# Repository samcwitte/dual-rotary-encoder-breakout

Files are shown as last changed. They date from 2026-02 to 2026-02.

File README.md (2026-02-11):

# dual-rotary-encoder-breakout
This is an open-source breakout PCB for the Bourns Inc. PEC11D-4120F-S0015 dual rotary encoder with switch.

This was made in KiCad 9.0.

All hardware and associated files are under the CERN Open Hardware Licence Version 2 - Permissive license.

All software and associated files are under the MIT license.

## Bill of Materials
Everything you'll need to make one yourself!

Alternative interactive BOM in `./ibom.html`

| | References | Value | Footprint | Quantity |
|---|---|---|---|---|
| 1 | R1, R2, R3, R4, R5, R6, R7, R8, R9 | 10K | 0603 (1608 Metric) | 9 |
| 2 | C1, C2, C3, C4 | 0.01u | 0603 (1608 Metric) | 4 |
| 3 | S1 | PEC11D-4120F-S0015 | PEC11D-4120F-S0015 Rotary Encoder | 1 |
| 4 | J3 | PINHD_1x7_Male | 2.54mm pitch header | 1 |

## Software Example

I used [Mike Teachman's micropython-rotary library](https://github.com/miketeachman/micropython-rotary) for some micropython code to run on a Raspberry Pi Pico.

You can find example code in `./software`. Be sure to use the latest version of Mike's library.

## 3D Render

preview-3d

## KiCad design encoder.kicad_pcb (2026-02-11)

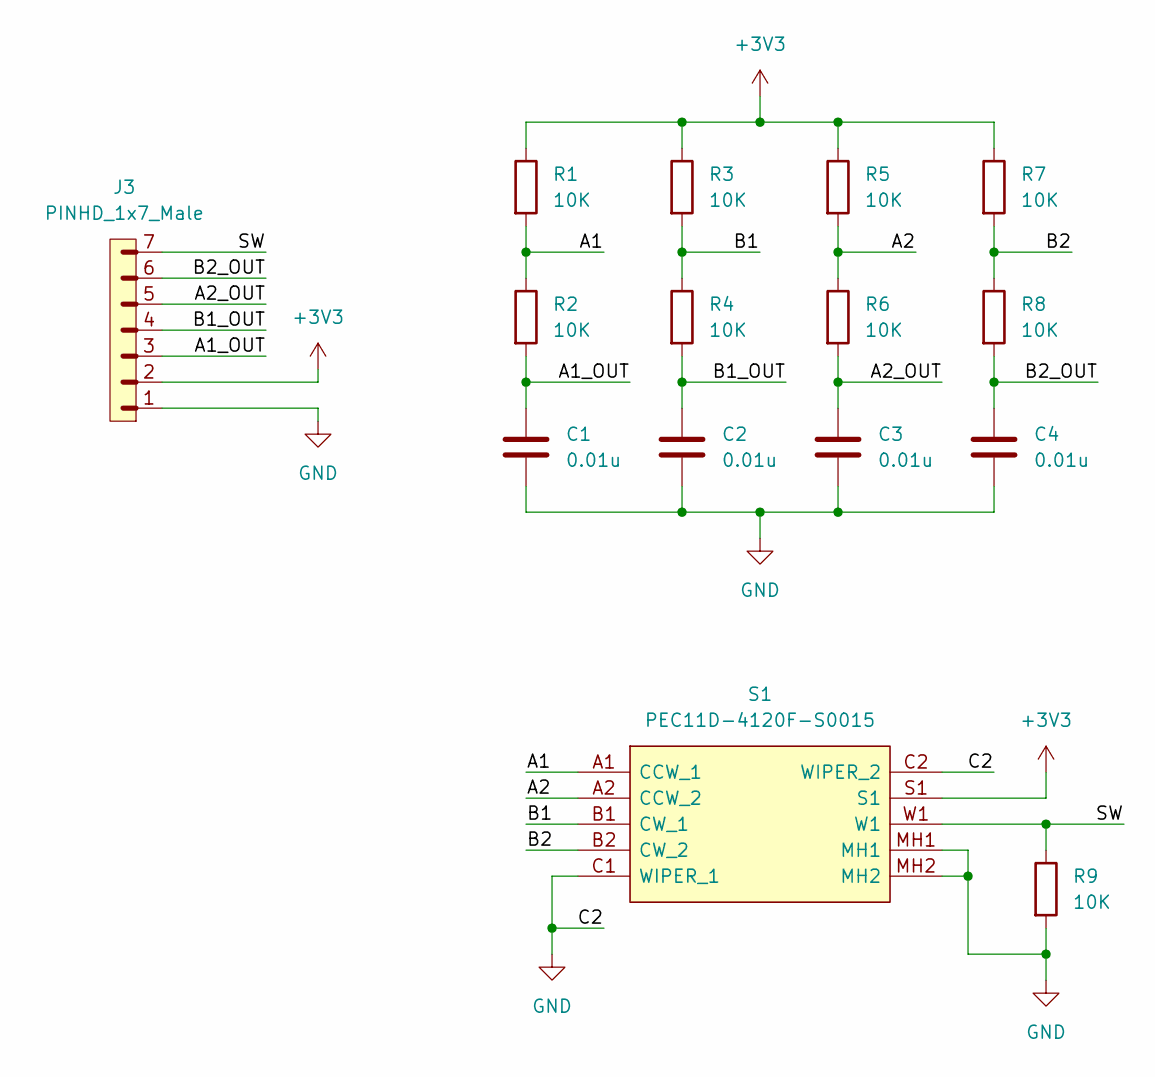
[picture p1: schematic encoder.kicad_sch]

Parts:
C1, C2, C3, C4: 0.01u; C_0603_1608Metric_Pad1.08x0.95mm_HandSolder; Part Number CL10B103KB8NNNC
J3: PINHD_1x7_Male; PinHeader_1x07_P2.54mm_Vertical
R1, R2, R3, R4, R5, R6, R7, R8, R9: 10K; R_0603_1608Metric_Pad0.98x0.95mm_HandSolder; Part Number AC0603FR-1310KL
S1: PEC11D-4120F-S0015; PEC11D-4120F-S0015 Rotary Encoder; Mouser Part Number 652-PEC11D4120FS0015

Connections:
+3V3: J3.2, R1.1, R3.1, R5.1, R7.1, S1.S1
/A1: R1.2, R2.1, S1.A1 (CCW_1)
/A1_OUT: C1.1, J3.3, R2.2
/A2: R5.2, R6.1, S1.A2 (CCW_2)
/A2_OUT: C3.1, J3.5, R6.2
/B1: R3.2, R4.1, S1.B1 (CW_1)
/B1_OUT: C2.1, J3.4, R4.2
/B2: R7.2, R8.1, S1.B2 (CW_2)
/B2_OUT: C4.1, J3.6, R8.2
/SW: J3.7, R9.1, S1.W1
GND: C1.2, C2.2, C3.2, C4.2, J3.1, R9.2, S1.C1 (WIPER_1), S1.C2 (WIPER_2), S1.MH1, S1.MH2

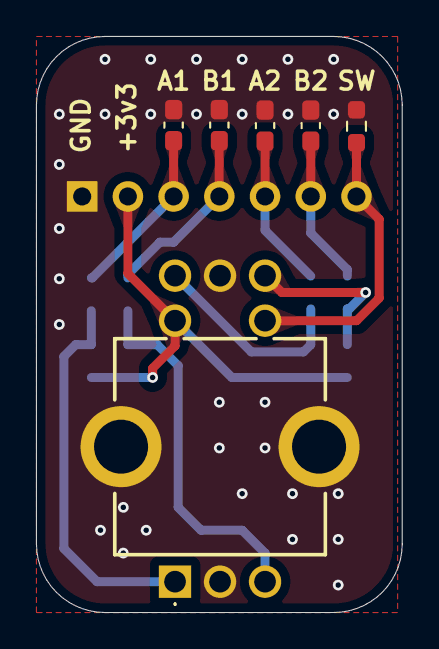
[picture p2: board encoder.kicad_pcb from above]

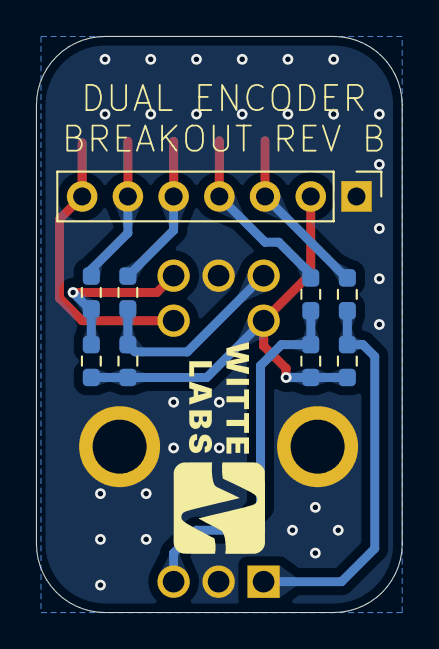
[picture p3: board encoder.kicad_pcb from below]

Board: 2 copper layers, 20.3 x 32.0 mm, 15 parts (9 on the bottom side), 11 nets.

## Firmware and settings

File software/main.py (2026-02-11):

# MIT License (MIT)
# Copyright (c) 2026 Samuel Witte
# https://opensource.org/licenses/MIT

# Example script for the Raspberry Pi Pico

# Documentation:
#   https://github.com/MikeTeachman/micropython-rotary

# This script holds two values - one for each rotary encoder

import time
from rotary_irq_rp2 import RotaryIRQ
from machine import Pin

pinA1 = 21
pinA2 = 20
pinB1 = 14
pinB2 = 15

sw = Pin(13, Pin.IN)

r1 = RotaryIRQ(pin_num_clk=pinA1, pin_num_dt=pinB1, min_val=0, max_val=99, reverse=False, half_step=True, pull_up=True, range_mode=RotaryIRQ.RANGE_BOUNDED)
r2 = RotaryIRQ(pin_num_clk=pinA2, pin_num_dt=pinB2, min_val=0, max_val=99, reverse=False, half_step=True, pull_up=True, range_mode=RotaryIRQ.RANGE_WRAP)

val_old1 = r1.value()
val_old2 = r2.value()

while True:
    try:
        val_new1 = r1.value()
        val_new2 = r2.value()
        
        if val_old1 != val_new1:
            val_old1 = val_new1
        
        if val_old2 != val_new2:
            val_old2 = val_new2
        
        if sw.value():
            print("click!")
            
        time.sleep_ms(50)
    except KeyboardInterrupt:
        break
